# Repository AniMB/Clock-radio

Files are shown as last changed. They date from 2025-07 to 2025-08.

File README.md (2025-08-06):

# ⏰ Clock Radio – MicroPython Smart Clock System

**`mi69.py`** is the main script of an embedded, Wi-Fi-enabled FM radio and smart clock interface built on **MicroPython**. It combines a **real-time clock**, **OLED UI**, **FM tuner**, and **web connectivity** into a single-threaded yet responsive application, suitable for microcontrollers like the Raspberry Pi Pico W.

---

## 🚦 Architecture Overview

```
             ┌────────────┐
             │   Button   │◄────────────┐
             └────┬───────┘             │
                  ▼                     │
             ┌─────────────┐     Debounce, Hold Detection
             │    Main     │─────────────┘
             │   (mi69.py) │
             └────┬────────┘
        ┌─────────┴─────────┐
        ▼                   ▼
┌────────────┐       ┌────────────┐
│  Display   │       │   Radio    │
│ (OLED + UI)│       │  (FM chip) │
└────┬───────┘       └────┬───────┘
     ▼                    ▼
 ┌──────────┐      ┌────────────┐
 │ Web Time │      │ Web Server │◄──── Access via browser
 └──────────┘      └────────────┘
```

---

## 🧠 Code Modules

### `mi69.py` – Main Control Loop

- Initializes components (RTC, FM radio, OLED, Button, Web).
- Sets up **interrupt-safe button handling** (short vs. long press).
- Periodically updates:
  - Display (clock, station, volume)
  - State file (`web_data.json`)
- Starts the **HTTP server in a separate thread**.

#### Core Mechanics

- `oled_dirty`, `json_dirty` flags minimize redundant writes
- `utime.ticks_ms()` is used to throttle updates
- JSON I/O and OLED are **locked via a thread-safe `_lock`**
- Long press (>3 sec) and debounce logic built-in

---

### `libraries/display.py` – OLED Drawing

Encapsulates all drawing on the OLED display using `framebuf`:

- `display_clock_time(rtc.datetime())`
- `display_radio_freq(101.9)`
- `display_volume(5)`

Also handles font scaling, screen clearing, and line placement.

---

### `libraries/radio.py` – FM Radio Control

Controls an FM tuner (likely via I2C/SPI). Key methods:

- `set_freq(freq)`: set frequency (MHz)
- `seek_up() / seek_down()`: scan for stations
- `set_volume(level)`: 0–15 volume levels

Keeps state internally for restoring or syncing with UI/web.

---

### `config/resources.py` – Global Shared State

Contains:

- Button pin definitions
- Flags: `oled_dirty`, `json_dirty`, `btn_short_req`, etc.
- Constants: debounce delay, hold time threshold
- A global `_lock` used by both threads

This is the “RAM” for the system shared across all modules.

---

### `web_connectivity/web.py` – HTTP Server

A simple HTTP server that runs on a new thread:

- Serves a web interface (to be extended)
- API routes:
  - `GET /status`: Return JSON state
  - `POST /set_time`, `POST /set_volume`, etc.
- Reads/writes `web_data.json` using the shared `_lock`

This lets users control and monitor the device remotely.

---

### `web_data.json` – State File

JSON-encoded structure for UI and web server to share state.

```json
{
  "volume": 5,
  "frequency": 101.9,
  "time": "12:34:56",
  "alarm_enabled": false
}
```

Used for persistence and as a synchronization bridge.

---

## 🧵 Concurrency & Thread Safety

- Uses MicroPython’s `_thread` module for background web server
- Ensures safety via `_lock` for:
  - JSON file access
  - OLED updates

```python
from _thread import start_new_thread
start_new_thread(WebServer().start, ())
```

---

## 🔋 Efficiency Considerations

- OLED and JSON updates are **rate-limited** using `ticks_ms()`
- Button reads are **debounced**
- Threads are **lightweight**, preventing blocking I/O
- Display refreshes only on changes

---

## 🚀 Future Extensions

- 📆 Alarm scheduling + snooze logic
- 🌐 NTP time sync
- 📱 Better web UI with sliders & buttons
- 📻 Station presets & memory
- 🔌 BLE or MQTT integration

---

## 📎 Developer Notes

- Clear modularity: `main`, `display`, `radio`, `web`, `resources`
- Code follows **embedded-safe design** (no dynamic memory abuse)
- Minimal, fast and effective for real-time low-power devices

---

## 🧠 Summary

This project is a highly educational template for combining hardware control, UI, web connectivity, and concurrency in **MicroPython**. It’s a complete working system for embedded devices with many real-world use cases.

---

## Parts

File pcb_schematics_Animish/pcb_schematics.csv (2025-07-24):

Reference | Value | Footprint | Datasheet | Qty | DNP | Exclude from BOM | Exclude from Board
C1,C2,C9,C10,C11,C14 | 0.01 µF | Capacitor_THT:C_Axial_L3.8mm_D2.6mm_P7.50mm_Horizontal | ~ | 6
C3,C6,C15,C16 | 470 µF | Capacitor_THT:CP_Radial_D6.3mm_P2.50mm | ~ | 4
C4,C5 | 0.05 µF | Capacitor_THT:C_Axial_L3.8mm_D2.6mm_P7.50mm_Horizontal | ~ | 2
C7,C8 | 0.1 µF | Capacitor_SMD:C_0603_1608Metric | ~ | 2
C12,C13 | 0.1 µF | Capacitor_THT:C_Axial_L3.8mm_D2.6mm_P7.50mm_Horizontal | ~ | 2
DISP1 | OLED Display | ECE:OLED_Display_1.3 |  | 1
H1,H2,H3,H4 | MountingHole | MountingHole:MountingHole_3.2mm_M3 | ~ | 4
J1 | CUE_SJ1-352XNG | Connector_PinHeader_2.54mm:PinHeader_1x05_P2.54mm_Vertical |  | 1
J2 | Conn_01x01_Pin | Connector_Pin:Pin_D1.0mm_L10.0mm_LooseFit | ~ | 1
J3,J4,J5 | Conn_01x05 | Connector_PinHeader_2.54mm:PinHeader_1x05_P2.54mm_Vertical | ~ | 3
LS1,LS2 | Speaker | TerminalBlock_Phoenix:TerminalBlock_Phoenix_MKDS-1,5-2_1x02_P5.00mm_Horizontal | ~ | 2
R1,R2 | 10Ω | Resistor_THT:R_Axial_DIN0207_L6.3mm_D2.5mm_P10.16mm_Horizontal | ~ | 2
R3,R4,R5,R6,R7,R8,R9,R10,R_Pullup1,R_Pullup2,R_Pullup3,R_Pullup4,R_Pullup5,R_Pullup6,R_Pullup7 | 10kΩ | Resistor_THT:R_Axial_DIN0207_L6.3mm_D2.5mm_P10.16mm_Horizontal | ~ | 15
Rpullup1,Rpullup2 | 2k | Resistor_THT:R_Axial_DIN0207_L6.3mm_D2.5mm_P10.16mm_Horizontal | ~ | 2
RV1,RV2 | 10kΩ | Connector_PinHeader_2.54mm:PinHeader_1x03_P2.54mm_Vertical | ~ | 2
SW1 | SW_Push | Connector_PinHeader_2.54mm:PinHeader_1x02_P2.54mm_Vertical | ~ | 1
TP1,TP2,TP3,TP4,TP5,TP6,TP7,TP8,TP9,TP10,TP11,TP12,TP13,TP14,TP15,TP16,TP17,TP18,TP19 | TestPoint | TestPoint:TestPoint_Keystone_5000-5004_Miniature | ~ | 19
U2 | RDA5807M_Module | ECE:RDA5807M_Module_TH |  | 1
U3,U4 | LM386 | LM386N_4:DIP794W45P254L1016H508Q8 | http://www.ti.com/lit/ds/symlink/lm386.pdf | 2
U5 | RPi_Pico_TH | ECE:RPi_Pico_TH |  | 1

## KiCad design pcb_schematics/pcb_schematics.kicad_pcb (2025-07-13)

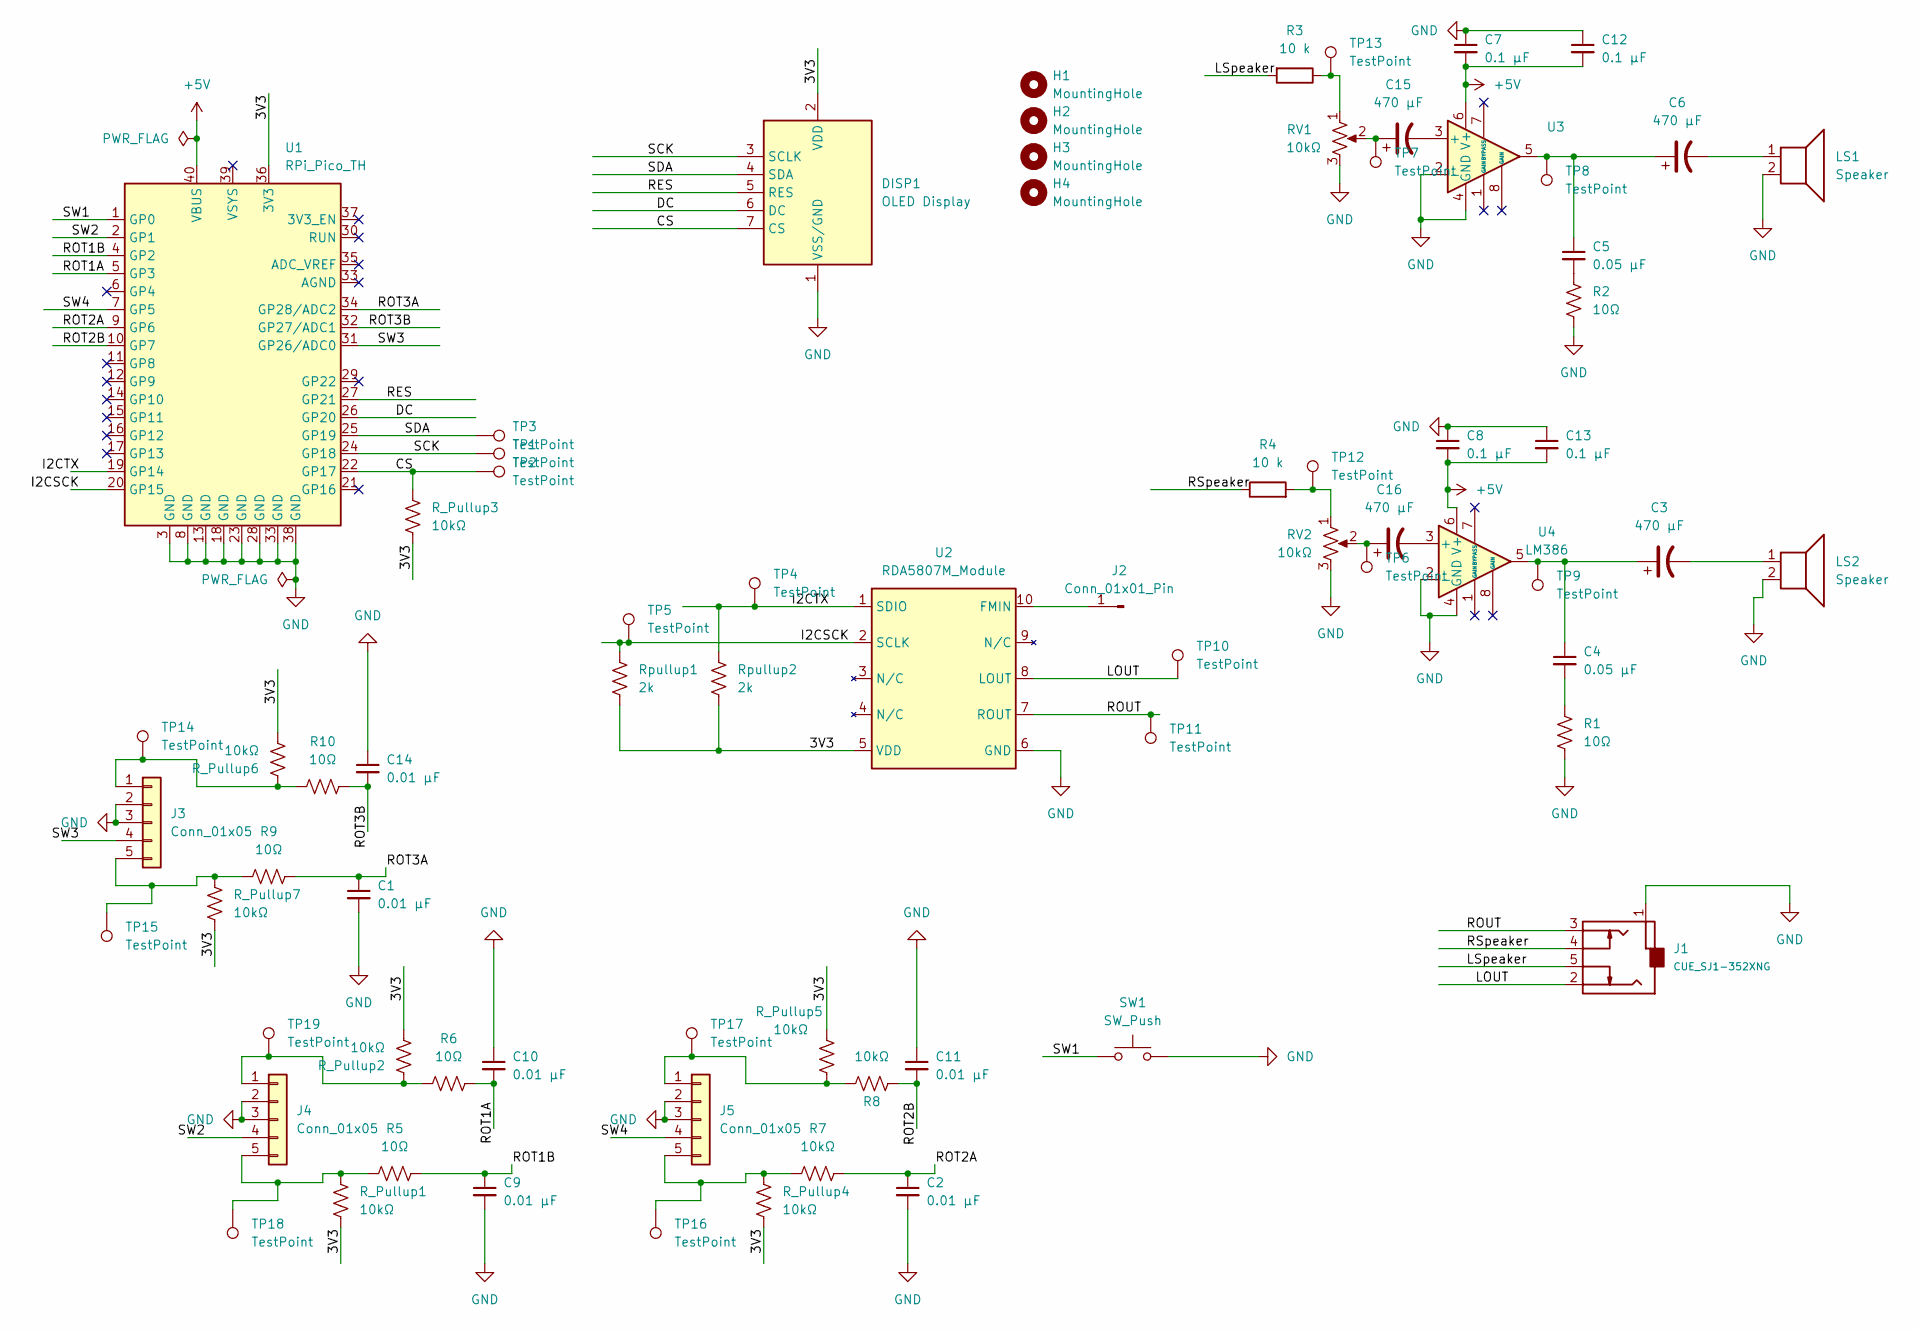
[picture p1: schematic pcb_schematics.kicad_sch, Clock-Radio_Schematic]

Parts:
C1, C2, C9, C10, C11, C14: 0.01 µF; C_Axial_L3.8mm_D2.6mm_P7.50mm_Horizontal
C3, C6, C15, C16: 470 µF; CP_Radial_D6.3mm_P2.50mm
C4, C5: 0.05 µF; C_Axial_L3.8mm_D2.6mm_P7.50mm_Horizontal
C7, C8: 0.1 µF; C_0603_1608Metric
C12, C13: 0.1 µF; C_Axial_L3.8mm_D2.6mm_P7.50mm_Horizontal
DISP1: OLED Display; OLED_Display_1.3
H1, H2, H3, H4: MountingHole; MountingHole_3.2mm_M3
J1: CUE_SJ1-352XNG; PinHeader_1x05_P2.54mm_Vertical
J2: Conn_01x01_Pin; Pin_D1.0mm_L10.0mm_LooseFit
J3, J4, J5: Conn_01x05; PinHeader_1x05_P2.54mm_Vertical
LS1, LS2: Speaker; TerminalBlock_Phoenix_MKDS-1,5-2_1x02_P5.00mm_Horizontal
R1, R2, R5, R6, R9, R10: 10Ω; R_Axial_DIN0207_L6.3mm_D2.5mm_P10.16mm_Horizontal
R3, R4: 10 k; R_Axial_DIN0207_L6.3mm_D2.5mm_P10.16mm_Horizontal
R7, R8: 10kΩ; R_Axial_DIN0207_L6.3mm_D2.5mm_P10.16mm_Horizontal
RV1, RV2: 10kΩ; PinHeader_1x03_P2.54mm_Vertical
R_Pullup1, R_Pullup2, R_Pullup3, R_Pullup4, R_Pullup5, R_Pullup6, R_Pullup7: 10kΩ; R_Axial_DIN0207_L6.3mm_D2.5mm_P10.16mm_Horizontal
Rpullup1, Rpullup2: 2k; R_Axial_DIN0207_L6.3mm_D2.5mm_P10.16mm_Horizontal
SW1: SW_Push; PinHeader_1x02_P2.54mm_Vertical
TP1, TP2, TP3, TP4, TP5, TP6, TP7, TP8, TP9, TP10, TP11, TP12, TP13, TP14, TP15, TP16, TP17, TP18, TP19: TestPoint; TestPoint_Keystone_5000-5004_Miniature
U1: RPi_Pico_TH
U2: RDA5807M_Module; RDA5807M_Module_TH
U3, U4: LM386; DIP794W45P254L1016H508Q8

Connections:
+5V: C7.2, C8.2, C12.2, C13.2, U1.40 (VBUS), U3.6 (V+), U4.6 (V+)
/3V3: DISP1.2 (VDD), R_Pullup1.2, R_Pullup2.2, R_Pullup3.2, R_Pullup4.2, R_Pullup5.2, R_Pullup6.2, R_Pullup7.2, Rpullup1.2, Rpullup2.2, U1.36 (3V3), U2.5 (VDD)
/CS: DISP1.7 (CS), R_Pullup3.1, TP2.1, U1.22 (GP17)
/DC: DISP1.6 (DC), U1.26 (GP20)
/I2CSCK: Rpullup1.1, TP5.1, U1.20 (GP15), U2.2 (SCLK)
/I2CTX: Rpullup2.1, TP4.1, U1.19 (GP14), U2.1 (SDIO)
/LOUT: J1.2 (Tip), TP10.1, U2.8 (LOUT)
/LSpeaker: J1.5 (Ring_Switch), R3.2
/RES: DISP1.5 (RES), U1.27 (GP21)
/ROT1A: C10.2, R6.1, U1.5 (GP3)
/ROT1B: C9.1, R5.2, U1.4 (GP2)
/ROT2A: C2.1, R7.2, U1.9 (GP6)
/ROT2B: C11.2, R8.1, U1.10 (GP7)
/ROT3A: C1.1, R9.2, U1.34 (GP28/ADC2)
/ROT3B: C14.2, R10.1, U1.32 (GP27/ADC1)
/ROUT: J1.3 (Tip), TP11.1, U2.7 (ROUT)
/RSpeaker: J1.4 (Tip_Switch), R4.1
/SCK: DISP1.3 (SCLK), TP1.1, U1.24 (GP18)
/SDA: DISP1.4 (SDA), TP3.1, U1.25 (GP19)
/SW1: SW1.1, U1.1 (GP0)
/SW2: J4.4, U1.2 (GP1)
/SW3: J3.4, U1.31 (GP26/ADC0)
/SW4: J5.4, U1.7 (GP5)
GND: C1.2, C2.2, C7.1, C8.1, C9.2, C10.1, C11.1, C12.1, C13.1, C14.1, DISP1.1 (VSS/GND), J1.1 (Sleeve), J3.2, J3.3, J4.2, J4.3, J5.2, J5.3, LS1.2, LS2.2, R1.2, R2.2, RV1.3, RV2.3, SW1.2, U1.3 (GND), U1.8 (GND), U1.13 (GND), U1.18 (GND), U1.23 (GND), U1.28 (GND), U1.33 (GND), U1.38 (GND), U2.6 (GND), U3.2 (-), U3.4 (GND), U4.2 (-), U4.4 (GND)
unnamed: C3.1, C4.1, TP9.1, U4.5
unnamed: C3.2, LS2.1
unnamed: C4.2, R1.1
unnamed: C5.1, C6.1, TP8.1, U3.5
unnamed: C5.2, R2.1
unnamed: C6.2, LS1.1
unnamed: C15.1, RV1.2, TP7.1
unnamed: C16.1, RV2.2, TP6.1
unnamed: J2.1, U2.10 (FMIN)
unnamed: J3.1, R10.2, R_Pullup6.1, TP14.1
unnamed: J3.5, R9.1, R_Pullup7.1, TP15.1
unnamed: J4.1, R6.2, R_Pullup2.1, TP19.1
unnamed: J4.5, R5.1, R_Pullup1.1, TP18.1
unnamed: J5.1, R8.2, R_Pullup5.1, TP17.1
unnamed: J5.5, R7.1, R_Pullup4.1, TP16.1
unnamed: R3.1, RV1.1, TP13.1
unnamed: R4.2, RV2.1, TP12.1
unnamed: C15.2, U3.3 (+)
unnamed: C16.2, U4.3 (+)

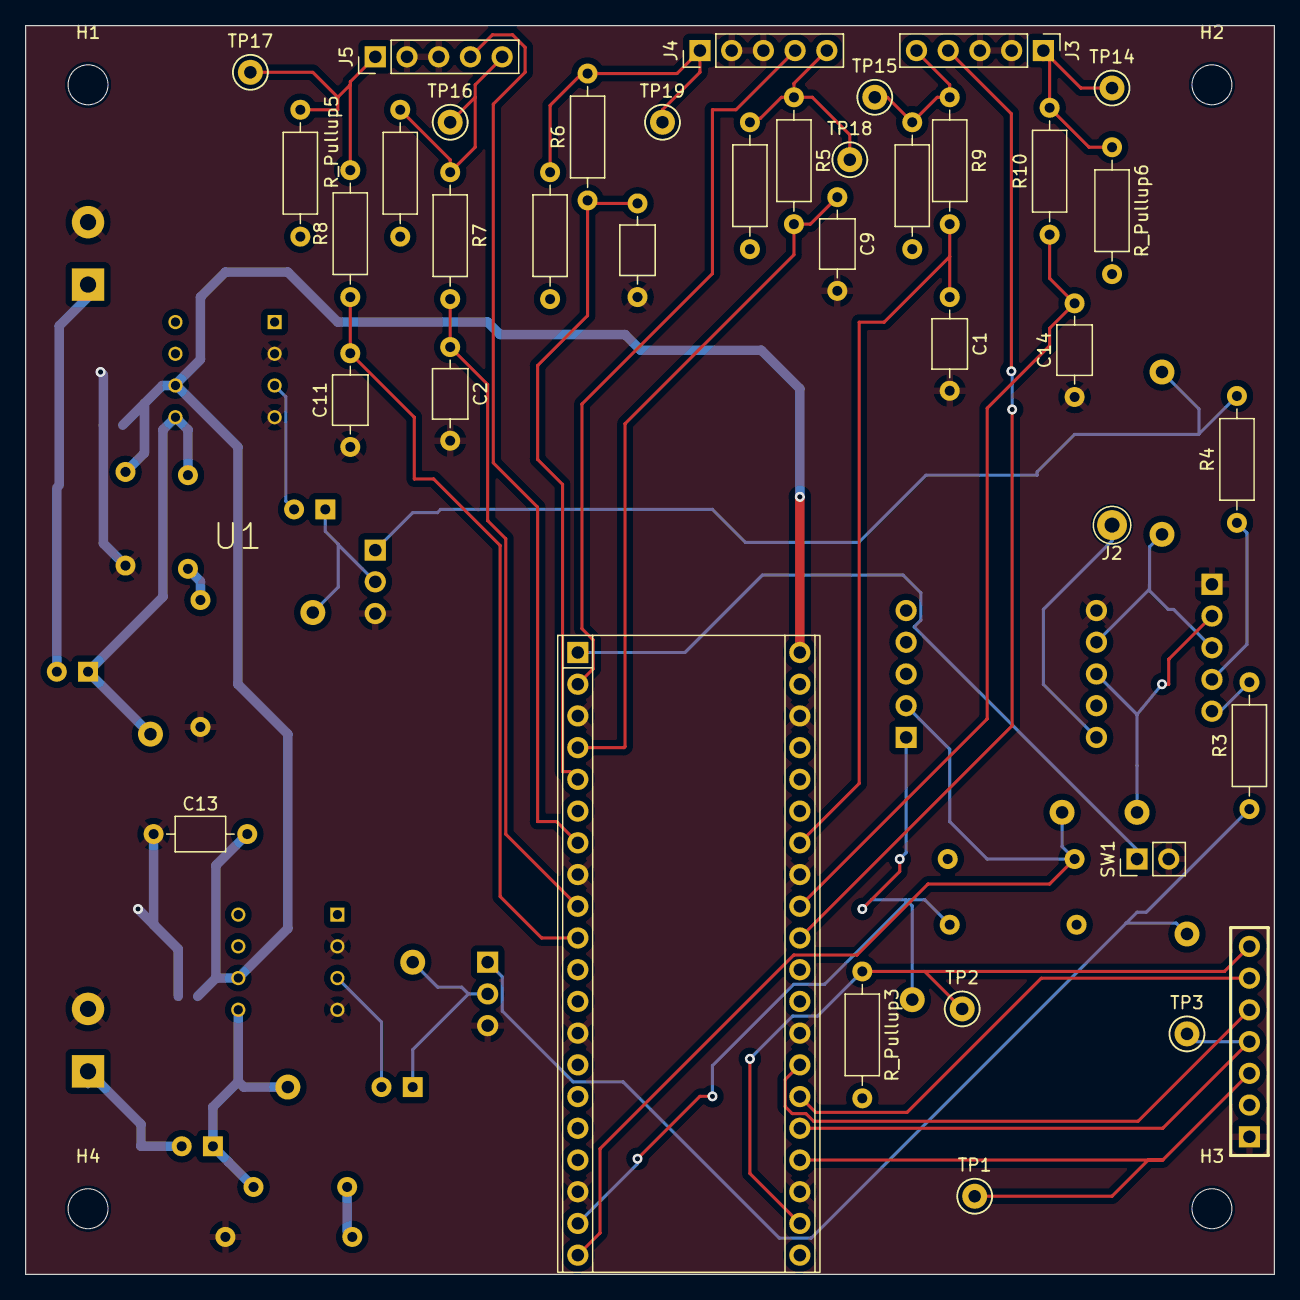
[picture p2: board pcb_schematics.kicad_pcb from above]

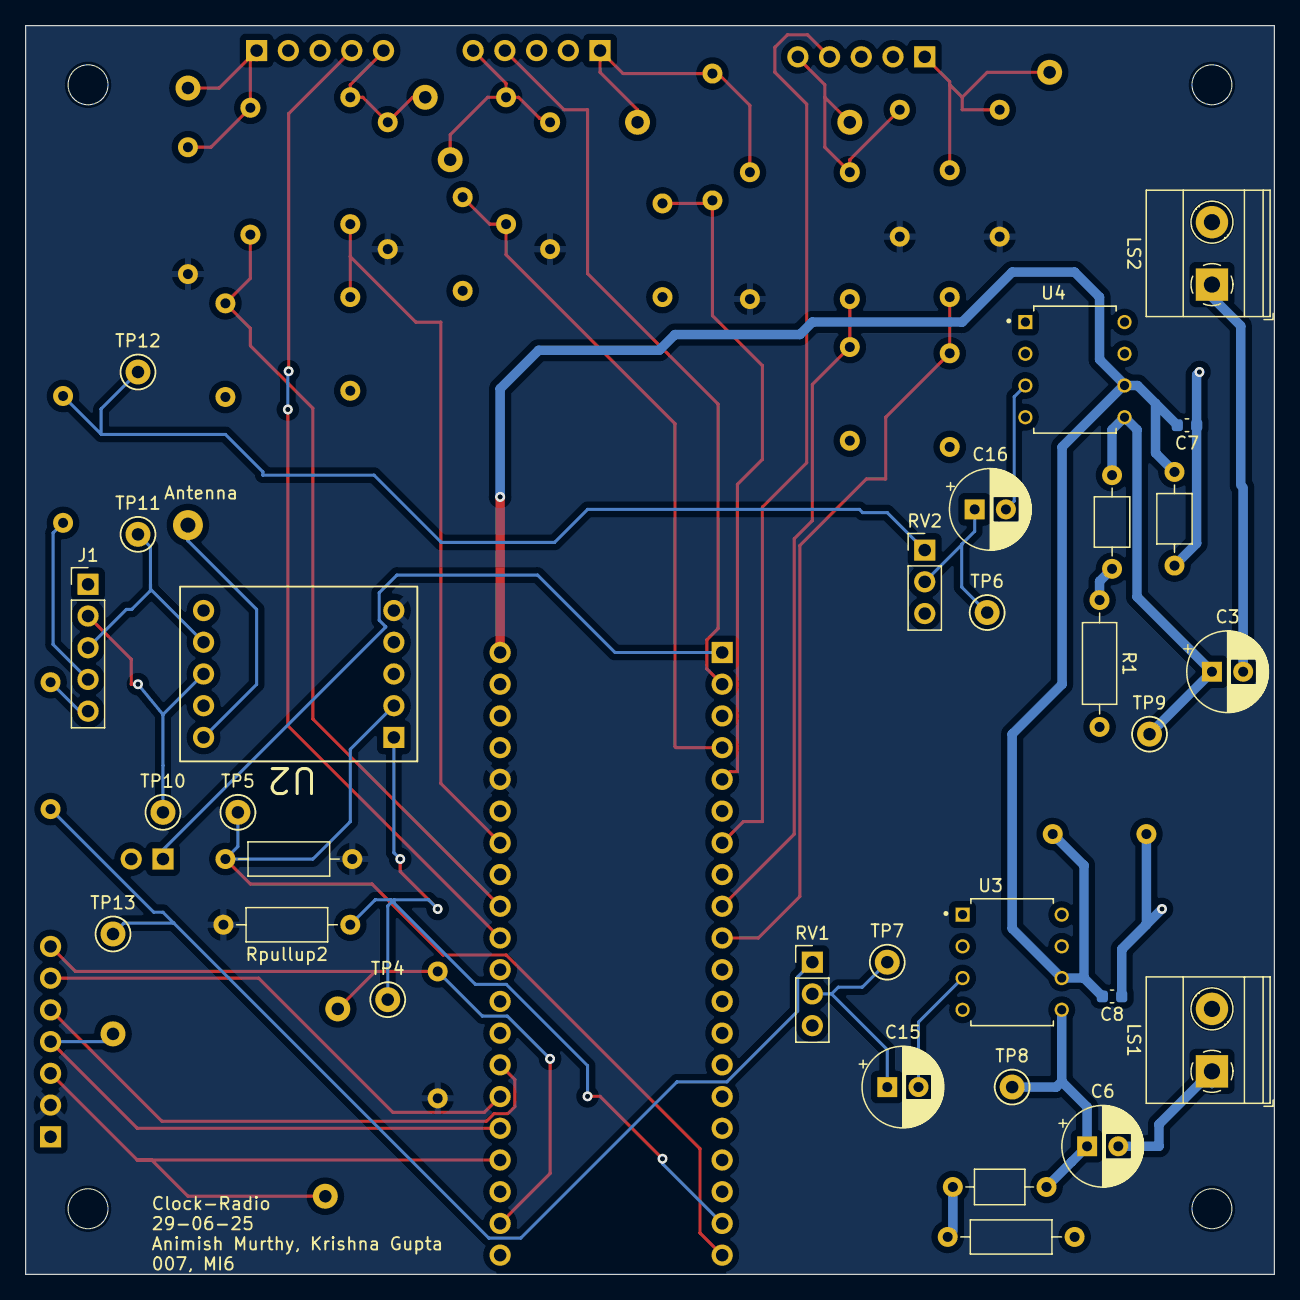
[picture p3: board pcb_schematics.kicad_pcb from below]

Board: 2 copper layers, 100.0 x 100.0 mm, 73 parts (31 on the bottom side), 43 nets.

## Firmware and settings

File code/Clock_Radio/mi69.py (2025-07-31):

import json
import os
import sys
import framebuf
import time

from machine import *
from utime import *
from _thread import *
from config.resources import *
from web_connectivity.web import WebServer
from config.resources import _lock
from network import WLAN, AP_IF
from libraries.display import *   # expects: oled, SCREEN_WIDTH, SCREEN_HEIGHT
from libraries.radio import Radio




import micropython
micropython.alloc_emergency_exception_buf(256)

# -------------------- RTC --------------------
rtc = RTC()

# -------------------- Button press policy --------------------
BUTTON_HOLD_MS = 3000  # long press threshold
_DEBOUNCE_MS   = 60

_btn_down_ms   = None
_btn_short_req = False
_btn_long_req  = False

# -------------------- Draw and JSON throttles --------------------
JSON_READ_PERIOD_MS  = 100
JSON_WRITE_PERIOD_MS = 250

_last_json_read_ms   = 0
_last_json_write_ms  = 0
_json_dirty          = False

_update_tick_due     = False
_last_drawn          = None
_oled_dirty          = False

# Yield policy to keep web thread responsive
_yield_count         = 0

# -------------------- Flags for modes --------------------
_snoozeflag = False
_alarmflag  = False
_Radioflag  = False

# =========================================================
#                        JSON
# =========================================================
class JsonHandler:
    def __init__(self):
        self.__filename = "web_data.json"
        self.json_object = {
            "alarm_hour": 0,
            "alarm_minute": 0,
            "alarm_ampm": 0,     # 0/1 or "AM"/"PM"
            "freq1": 101.9,
            "freq2": 101.9,
            "freq3": 101.9,
            "volume": 50,
            "nowplaying": 1,
            "use24Hour": 1,
            "mute": 0,
            "Time": "12:00:00",
            "time_ampm": 0,
            "snooze": 5,
            "cancelAlarm": 0
        }

    def read_json(self) -> bool:
        if _lock.acquire():
            try:
                with open(self.__filename, "r") as file:
                    data = json.load(file)
                self.json_object.clear()
                self.json_object.update(data)
                return True
            except Exception as e:
                # Keep it quiet in hot path
                # print(f"Error reading from {self.__filename}: {e}")
                return False
            finally:
                _lock.release()
        else:
            # print("Lock busy on read")
            return False

    def write_json(self) -> bool:
        if _lock.acquire():
            try:
                with open(self.__filename, "w") as file:
                    json.dump(self.json_object, file)
                return True
            except Exception as e:
                # print(f"Error writing to {self.__filename}: {e}")
                return False
            finally:
                _lock.release()
        else:
            # print("Lock busy on write")
            return False

# =========================================================
#                        Time
# =========================================================
def increment_and_update_time(value_dict):
    try:
        timestr = value_dict.get("Time", "00:00:00").strip()
        h, m, s = map(int, timestr.split(":"))
        s += 1
        if s >= 60:
            s = 0
            m += 1
            if m >= 60:
                m = 0
                h += 1
                if h >= 24:
                    h = 0
        value_dict["Time"] = f"{h:02}:{m:02}:{s:02}"
        if value_dict.get("use24Hour", 1) == 0:
            ampm = "AM" if h < 12 else "PM"
            hh = h % 12 or 12
            time_str = f"{hh:02}:{m:02}:{s:02}"
        else:
            ampm = ""
            time_str = f"{h:02}:{m:02}:{s:02}"
        return time_str, ampm
    except Exception as e:
        # print(f"Error incrementing time: {e}")
        return value_dict.get("Time", "00:00:00"), ""

# =========================================================
#                        Hardware
# =========================================================
button = Pin(0, Pin.IN, Pin.PULL_UP)

handle_json = JsonHandler()
if not handle_json.read_json():
    handle_json.write_json()
value_dict = handle_json.json_object

# clamp nowplaying to 1..3
_idx = int(value_dict.get("nowplaying", 1))
if _idx < 1 or _idx > 3:
    _idx = 1

fm_radio = Radio(
    float(value_dict.get(f"freq{_idx}", 100.0)),
    int(value_dict.get("volume", 50)),
    int(value_dict.get("mute", 0))
)

# =========================================================
#                        Drawing
# =========================================================
def draw_clock(time_str, ampm):
    global _last_drawn, _update_tick_due, _oled_dirty
    stamp = (time_str, ampm)
    if stamp == _last_drawn:
        return
    _last_drawn = stamp
    _update_tick_due = False

    oled.fill(0)
    oled.text(time_str, 0, 0)
    if ampm:
        oled.text(ampm, 80, 0)
    _oled_dirty = True

def _show_volume(vol, mute):
    global _oled_dirty
    bar_h = 5
    y0 = SCREEN_HEIGHT - bar_h
    oled.fill_rect(0, y0, SCREEN_WIDTH, bar_h, 0)
    try:
        vol = int(vol)
    except Exception:
        vol = 0
    if vol < 0:
        vol = 0
    if vol > 100:
        vol = 100
    fill_w = 0 if int(mute) else int((vol / 100.0) * SCREEN_WIDTH)
    oled.fill_rect(0, y0, fill_w, bar_h, 1)
    oled.rect(0, y0, SCREEN_WIDTH, bar_h, 1)
    _oled_dirty = True

# =========================================================
#                        Timer and Button IRQ
# =========================================================
def on_timeout(t):
    # IRQ safe
    global _update_tick_due
    _update_tick_due = True

timer = Timer(-1)
timer.init(period=1000, mode=Timer.PERIODIC, callback=on_timeout)

def _button_irq(pin):
    global _btn_down_ms, _btn_short_req, _btn_long_req
    now = ticks_ms()
    if pin.value() == 0:  # pressed
        if _btn_down_ms is None:
            _btn_down_ms = now
    else:  # released
        if _btn_down_ms is not None:
            dur = ticks_diff(now, _btn_down_ms)
            _btn_down_ms = None
            if dur >= BUTTON_HOLD_MS:
                _btn_long_req = True
            elif dur >= _DEBOUNCE_MS:
                _btn_short_req = True
    

button.irq(trigger=Pin.IRQ_FALLING | Pin.IRQ_RISING, handler=_button_irq, hard=True)

# =========================================================
#                        Alarm
# =========================================================
class Alarm:
    alarm_h = 0
    alarm_m = 0

    def __init__(self):
        # remember the last (hour, minute) we triggered in to avoid retrigger spam
        self._last_triggered_min = None

    @staticmethod
    def to_24h(hour: int, minute: int, am_pm: str) -> tuple:
        hour = int(hour); minute = int(minute)
        tag = str(am_pm).strip().upper()
        if tag not in ("AM", "PM"):
            raise ValueError("am_pm must be 'AM' or 'PM'")
        if not (1 <= hour <= 12):
            raise ValueError("hour 1..12")
        if not (0 <= minute <= 59):
            raise ValueError("minute 0..59")
        if tag == "AM":
            h24 = 0 if hour == 12 else hour
        else:
            h24 = 12 if hour == 12 else hour + 12
        return h24, minute

    def _normalize_alarm_from_dict(self, value_dict):
        """
        Normalize alarm fields to 24h regardless of display mode.
        If we have AM/PM and hour looks 12h (1..12), convert.
        Otherwise assume it's already 24h.
        """
        h = int(value_dict.get("alarm_hour", 0))
        m = int(value_dict.get("alarm_minute", 0))
        ampm = value_dict.get("alarm_ampm", None)

        # Accept int 0/1 or string AM/PM
        if isinstance(ampm, int):
            ampm = "PM" if ampm else "AM"

        if 1 <= h <= 12 and ampm in ("AM", "PM"):
            try:
                h, m = self.to_24h(h, m, ampm)
            except Exception:
                pass  # fall back to given values on error

        return h, m

    def sync_from_dict(self, value_dict):
        self.snooze_minutes = int(value_dict.get("snooze", 5))
        self.alarm_enabled  = not bool(int(value_dict.get("cancelAlarm", 0)))

        # Normalize alarm to 24h unconditionally when we can infer AM/PM
        self.alarm_hour, self.alarm_minute = self._normalize_alarm_from_dict(value_dict)

        Alarm.alarm_h = self.alarm_hour
        Alarm.alarm_m = self.alarm_minute
        # do not reset self._last_triggered_min here; it is a per-minute guard

    def is_alarm(self, value_dict) -> bool:
        """
        Returns True exactly once when current (h,m) equals the scheduled alarm time.
        If we were snoozing, clear the snooze flag at the moment we reach the time.
        """
        if not self.alarm_enabled:
            return False

        h, m, _ =  value_dict["Time"].strip().split(":")

        h,m=int(h),int(m)
        now_min = (int(h),int( m))

        if (self.alarm_hour == h) and (self.alarm_minute == m):
            # if we were snoozing, it's time to wake up again
            global _snoozeflag
            if _snoozeflag:
                _snoozeflag = False

            # trigger only once per minute
            if self._last_triggered_min != now_min:
                self._last_triggered_min = now_min
                return True
            else:
                return False
        else:
            # reset guard when minute moves away from the alarm time
            if self._last_triggered_min == now_min:
                # still in same minute but not the alarm minute; keep guard
                pass
            return False

    def on_snooze(self):
        """
        Short press: stop ringing and schedule next ring after snooze_minutes.
        """
        global _snoozeflag, _alarmflag
        if not _alarmflag:
            return
        _snoozeflag = True
        _alarmflag  = False
        try:
            fm_radio.SetMute(True)
            fm_radio.ProgramRadio()
        except Exception:
            pass

      

        h,m=self.alarm_hour, self.alarm_minute
        total = h * 60 + m + int(self.snooze_minutes)
        self.alarm_hour   = (total // 60) % 24
        self.alarm_minute = total % 60

        # allow a new trigger when snooze time arrives
        self._last_triggered_min = None

    def stop_alarm(self):
        """
        Long press: fully stop, disarm, and allow future arming.
        """
        global _snoozeflag, _alarmflag
        _snoozeflag = False
        _alarmflag  = False
        self.alarm_enabled = False
        self._last_triggered_min = None
        try:
            fm_radio.SetMute(True)
            fm_radio.ProgramRadio()
        except Exception:
            pass

alarm = Alarm()

def on_stop(value_dict):
    global alarm, _json_dirty
    alarm.stop_alarm()
    value_dict["cancelAlarm"] = 1  # persist disarm
    _json_dirty = True
    alarm = Alarm()

# =========================================================
#                        Main loop
# =========================================================
def pico_runner():
    global _snoozeflag, _Radioflag, _alarmflag
    global _last_json_read_ms, _last_json_write_ms, _json_dirty
    global _update_tick_due, _oled_dirty, _yield_count

    # Ensure JSON exists
    if not handle_json.read_json():
        handle_json.write_json()
    value_dict = handle_json.json_object

    while True:
        now = ticks_ms()

        # Throttled JSON read
        if ticks_diff(now, _last_json_read_ms) >= JSON_READ_PERIOD_MS:
            handle_json.read_json()
            value_dict = handle_json.json_object
            _last_json_read_ms = now

        # Consume button requests
        global _btn_short_req, _btn_long_req
        if _btn_long_req and _alarmflag:
            _btn_long_req = False
            on_stop(value_dict)
            print("button pressed")
        elif _btn_short_req and _alarmflag:
            _btn_short_req = False
            alarm.on_snooze()
            print("button pressed")
        elif _btn_short_req and _Radioflag:
            _btn_short_req = False
            _Radioflag = False
            print("button pressed")
            # turn radio OFF (mute)
            fm_radio.SetMute(1)
            fm_radio.ProgramRadio()

        elif _btn_short_req and not _Radioflag:
            _btn_short_req = False
            _Radioflag = True
            print("button pressed")
            # turn radio ON: tune and unmute immediately
            idx  = max(1, min(3, int(value_dict.get("nowplaying", 1))))
            freq = float(value_dict.get(f"freq{idx}", 100.0))
            fm_radio.SetFrequency(freq)
            fm_radio.SetVolume(value_dict.get("volume", 50))
            fm_radio.SetMute(0)
            fm_radio.ProgramRadio()



        # Sync alarm when not snoozing
        if not _snoozeflag:
            alarm.sync_from_dict(value_dict)

        # 1 Hz clock tick
        if _update_tick_due:
            _update_tick_due = False
            time_str, ampm = increment_and_update_time(value_dict)
            draw_clock(time_str, ampm)
            _json_dirty = True

        # Trigger alarm (after the latest tick)
        if alarm.is_alarm(value_dict):
            _alarmflag = True
            _Radioflag = False
            print("alarm triggered")
            fm_radio.SetFrequency(100.1)
            fm_radio.SetVolume(100)
            fm_radio.SetMute(0)
            fm_radio.ProgramRadio()


        # Radio UI and tuning only when showing radio and not ringing
        if _Radioflag and not _alarmflag:
            idx  = max(1, min(3, int(value_dict.get("nowplaying", 1))))
            freq = float(value_dict.get(f"freq{idx}", 100.0))

            # Only reprogram radio when something actually changed
            need = False
            if int(value_dict.get("mute", 0))   != int(fm_radio.Mute):   need = True
      
            desired_hw = (int(value_dict.get("volume", 50)) * 15 + 50) // 100  # rounded
            if desired_hw != int(fm_radio.Volume):
                need = True
            if abs(freq - float(fm_radio.Frequency)) > 1e-3:             need = True

            if need:
                fm_radio.SetMute(value_dict.get("mute", 0))
                fm_radio.SetVolume(value_dict.get("volume", 50))
                fm_radio.SetFrequency(freq)
                fm_radio.ProgramRadio()

            oled.fill_rect(0, 10, SCREEN_WIDTH, 10, 0)
            oled.text("Now:", 0, 10)
            oled.text("{:.1f}MHz".format(freq), 40, 10)
            _oled_dirty = True
        else:
            if _Radioflag:   # cleared this cycle
                _Radioflag = False
                oled.fill_rect(0, 10, SCREEN_WIDTH, 10, 0)
                _oled_dirty = True

        if _lock.locked():
            oled.text("locked", 80,30)

        # Volume bar
        _show_volume(value_dict["volume"], value_dict["mute"])

        # Flush OLED only if it changed
        if _oled_dirty:
            _oled_dirty = False
            oled.show()

        # Throttled JSON write
        if _json_dirty and ticks_diff(now, _last_json_write_ms) >= JSON_WRITE_PERIOD_MS:
            if handle_json.write_json():
                _json_dirty = False
                _last_json_write_ms = now

        # Cooperative yield so web thread runs
        if _alarmflag or _Radioflag:
            sleep_ms(0)
        else:
            _yield_count = (_yield_count + 1) & 31
            if _yield_count == 0:
                sleep_ms(1)
            else:
                sleep_ms(0)

def main():
    ssid = '007'
    password = '212173314'
    ap = WLAN(AP_IF)
    ap.config(essid=ssid, password=password)
    ap.active(True)
    while ap.active() == False:
        pass
    print('Connection is successful')
    print(ap.ifconfig())

    Worker = WebServer()
    start_new_thread(Worker.runner, ())
    pico_runner()

if __name__ == "__main__":
    main()

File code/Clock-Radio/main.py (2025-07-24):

import json
import os
import sys
from machine import Pin
from utime import *
from _thread import *
from config.resources import *
from web_connectivity.web import WebServer
from typing import Any
from config.resources import _lock
from network import WLAN, AP_IF



"""Make a read json write json function that uses a lock to ensure thread safety. This will be for the main.py file."""
class JsonHandler:
    def __init__(self):
        self.__filename = "database/web_data.json"
        self.__lock = _lock
        self.json_object = {}

    def read_json(self) ->bool:
        if self.__lock.acquire(blocking=False):

            try:
                with open(self.__filename, 'r') as file:
                    self.json_object= json.load(file)  
                return True
            except FileNotFoundError:
                print(f"File {self.__filename} not found.")
                return False
            except json.JSONDecodeError as e:
                print(f"Error decoding JSON from {self.__filename}: {e}")
                return False
        else:
            print("Lock is already acquired, cannot read JSON file.")
            return False

    def write_json(self) -> bool:
        if self.__lock.acquire(blocking=False):

            try:
                with open(self.__filename, 'w') as file:
                    json.dump(self.json_object, file, indent=4)  # type: ignore
                return True
            except Exception as e:
                print(f"Error writing to {self.__filename}: {e}")
                return False
        else:
            print("Lock is already acquired, cannot write JSON file.")
            return False  



"""The main needs to have a time.sleep(0). This is to yield control to the web server.
This is because the web server runs in a while loop and needs to be able to process requests"""
def pico_runner():
    handle_json = JsonHandler()
    handle_json.read_json()
    value_dict = handle_json.json_object

    '''User Code begins here'''








    '''User Code ends here'''


    handle_json.write_json()



def main():
    # --------------------------------------------------------------------------
    # Below given code should not be modified (except for the name of ssid and password). 
    # Create a network connection
    ssid = '007'       #Set access point name 
    password = '12345678'      #Set your access point password
    ap = WLAN(AP_IF)
    ap.config(essid=ssid, password=password)
    ap.active(True)            #activating

    while ap.active() == False:
        pass
    print('Connection is successful')
    print(ap.ifconfig())
    pico_runner()
    Worker = WebServer()
    start_new_thread(Worker.runner,())    
    
    sleep_ms(0) # Yield control to the web server to be added when reading or writing to the JSON file
    
            





if __name__=="__main__":
    main()

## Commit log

2025-06-27 Adding PCB schematics
    [pcb_schematics.kicad_pcb, pcb_schematics.kicad_sch]
2025-07-13 Pcb (#1)
    * Converted to connectors
    * Updates PCb according to ROB's feedback
    Added PCb layour according to the discussion with butoons and display on top and display below using front copper. Added Radio module using back copper. Speakers left to set up using back copper.
    * compeltes PCB
    Only the DRC has a couple errors
    * Updates footprints in schematic
    * Fixes errors in DRC
    Adds SMD capacitors too
    * Runs DRC and ERC again
    * Accomodating usb cable
    * Revision 3
    Changed the amplifier and the rotary encoder schemtic. Needs work on pcb
    * completes third version of PCB
    * fixed issues mentioned by rob and brent
    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
    [pcb_schematics-B_Cu.gbr, pcb_schematics-B_Mask.gbr, pcb_schematics-B_Paste.gbr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]
2025-07-13 Pm (#3)
    Fix iteration 1
    * made changes based on changes requested
    Fix iteration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
    [Gantt chart.xlsx, pcb_schematics.kicad_pcb, pcb_schematics.kicad_sch]
2025-07-21 Converted to connectors
2025-07-21 Updates PCb according to ROB's feedback
    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
2025-07-21 compeltes PCB
    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
2025-07-21 Updates footprints in schematic
2025-07-21 Fixes errors in DRC
    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
2025-07-21 Runs DRC and ERC again
    [pcb_schematics.kicad_pcb]
2025-07-21 Accomodating usb cable
    [pcb_schematics.kicad_pcb]
2025-07-21 Revision 3
    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
    [pcb_schematics.kicad_sch]
2025-07-21 completes third version of PCB
    [pcb_schematics.kicad_pcb, pcb_schematics.kicad_sch]
2025-07-21 fixed issues mentioned by rob and brent
    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
    [pcb_schematics.kicad_pcb, pcb_schematics.kicad_sch]
2025-07-21 made changes based on changes requested
    Fix iteration 2
    [pcb_schematics.kicad_pcb, pcb_schematics.kicad_sch]
2025-07-21 Submitted to JLCPCB
    Modification with pcb_schematics being the final version.
    [pcb_schematics.kicad_pcb, pcb_schematics.kicad_sch]
2025-07-21 Adds Ganntt chart
    [Gantt chart.xlsx]
2025-07-21 Update Gantt chart.xlsx
    [Gantt chart.xlsx]
2025-07-21 cleans the code
    [pcb_schematics.kicad_pcb, pcb_schematics.kicad_sch]
2025-07-21 Fixes the web.py.
    Needs a webpage and a js file
    [pcb_schematics.kicad_sch]
2025-07-21 modified the webpage and set up the main files
    [pcb_schematics.csv, pcb_schematics.kicad_sch]
2025-07-25 makes a connection but js fails to load
    [mi69.py, web.py]
2025-07-26 FIxed import and blocking errors
    [mi69.py, web.py]
2025-07-27 fixes errors and allows entire request to be processed
    [mi69.py, web.py]
2025-07-29 Creates major chnages
    Requires work to be done of alarm. THen to work on radio alarm button
2025-07-29 fixes bugs and adds time
    [mi69.py]
2025-07-30 Fixed comment and addds rtc time
    [mi69.py]
2025-07-30 Revert "Completes the code with locked visible"
    This reverts commit 778d3d012da1678581d6e8521fdcfdb85e9801f0.
    [mi69.py]
2025-07-30 Revert "Fixed comment and addds rtc time"
    This reverts commit 116130d8c3e0ab863ebd2706c4f76c6ead57e4d2.
    [mi69.py]
2025-07-30 Reapply "Completes the code with locked visible"
    This reverts commit 0901dce5da3b9b6a84a9f30ec13ec27c314d50b2.
    [mi69.py]
2025-08-05 Cleaing code
    [Gantt chart.xlsx]
